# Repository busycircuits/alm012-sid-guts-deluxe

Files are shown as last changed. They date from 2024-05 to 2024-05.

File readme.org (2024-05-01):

* ALM012 SID GUTS DELUXE

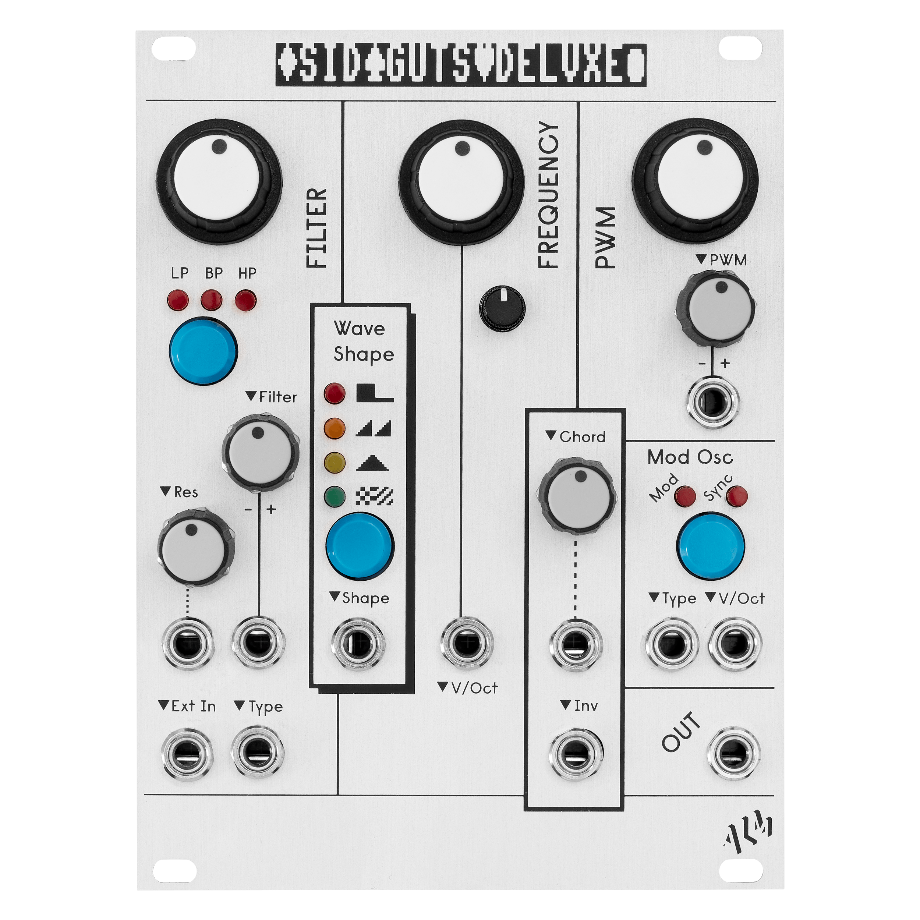
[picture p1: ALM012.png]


** Introduction

The MOS Technology 6581/8580 ‘Sound Interface Device’ chip, aka the ‘SID’, was the sound generator chip used in the Commodore 64 home computer – the greatest selling home computer of all time.  The SID, by the means of 3 wavetable oscillators, a real analogue multi mode filter, an ADSR and various cross modulation options, provided the soundtrack to a generations gaming and perhaps many peoples first exposure to real sound synthesis. The SID’s unique musical aesthetic has lasted well beyond the lifetime of the C64 re-imagined in standalone products such as the SID Station and with in the computer via sophisticated software emulation.

The ALM Busy Circuits ‘SID GUTS DELUXE’ takes the legendary SID chip and brings it into the eurorack modular environment. By use of a real (or emulated) SID chip the classic sound is taken in a new direction with the levels of direct and voltage control only a modular system can offer.

The module features voltage control over numerous SID parameters including the classic PWM, Filter type, cut off, resonance and external input, waveform selection, secondary mod oscillator with ring and sync modulation, voltage per octave tracking and a 3 voice chord mode with inversion. 

The ‘SID GUTS DELUXE’ improves upon the original SID GUTS and was originally released 2014. In 2024 we ended production and have made the firmware and design files open source for anyone to build their own derivative. The files are available in this repository. 

Note you will need a donor SID chip for the module to work. Any real SID chip should work as should most emulated clones (Swin Sid etc). 

*PLEASE NOTE EVERYTHING IS PROVIDED AS IS. WE ARE UNABLE PROVIDE ANY SUPPORT TO ANYONE ATTEMPTING TO USE THESE FILES*

** Building and flashing the firmware

You'll need a basic 'usbtiny' AVR programmer.

You'll need to install avr-gcc and avrdude.

/(On mac using brew..)/
#+BEGIN_SRC
brew tap osx-cross/avr
brew install avr-gcc
brew install avrdude
#+END_SRC

Type 'make' in the firmare/ directory to compile the source code and
then run 'make ispload' (with your programmer connected) to program the
SID GUTS.

** License

Code: MIT license.

Hardware: cc-by-sa-3.0

** Guidelines for derivative works

*ALM is a registered trademark.*

The name "ALM" should not be used on any of the derivative works you create from these files.

We kindly ask to do not name any derivatives 'SID GUTS' but give it a new name.

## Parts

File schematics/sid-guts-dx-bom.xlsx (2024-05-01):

Qty | Parts | Value | Device | Package | SOLDERED REAR | Description / Notes | Mouser Part Num | RS Part Num | Other Part Num
7 | CHORD, FILTER, FILTER_ATT, FREQ_COARSE, PWM_ATTR, PWM_OFF, RES | 10K | ALPHA-9MMA | EVUF |  | 9 mm Square Rotary Potentiometers
1 | FREQ_FINE | 10K | ALPHA-9MMA |  |  | knurled 9 mm Square Rotary Potentiometer
1 | VCO_TRIM | 10K | TRIM_1234-S64YW | S64YW | Y | Trimmer | 72-T93YB-10K
22 | R2, R4, R9, R10, R12, R13, R14, R22, R25, R29, R31, R32, R33, R34, R36, R39, R41, R42, R44, R58, R60, R76 | 100K | RESISTOR0603 | R0603
1 | R49 | 150k | RESISTOR0603 | R0603
12 | R1, R3, R5, R7, R8, R11, R21, R23, R27, R28, R30, R43 | 10K | RESISTOR0603 | R0603
1 | R24 | 200K | RESISTOR0603 | R0603
9 | R80, R81, R82, R83, R16, R17, R18, R19, R20 | 330 | RESISTOR0603 | R0603
4 | R26, R37, R63, R62 | 2.2K | RESISTOR0603 | R0603
1 | R38 | 1K | RESISTOR0603 | R0603
1 | R57 | 1M | RESISTOR0603 | R0603
1 | R6 | 1k | RESISTOR0603 | R0603
3 | R15, R35, R40 | 49.9k | RESISTOR0603 | R0603
1 | R59 | 43K | RESISTOR0603 | R0603
19 | C3, C7, C8, C9, C13, C14, C15, C16, C17, C18, C22, C23, C24, C25, C26, C27, C29, C31, C32 | 100n | CAPACITOR0603 | C0603
3 | C30, C11, C21 | 1n | CAPACITOR0603 | C0603
3 | C6, C10, C28 | 1uf | CPOL-EUB | PANASONIC_B |  | POLARIZED CAPACITOR, European symbol
3 | C1, C2, C12 | 10uf | CPOL-EUB | PANASONIC_B |  | POLARIZED CAPACITOR, European symbol
2 | C19, C20 | 18pf | CAPACITOR0603 | C0603
1 | IC4 | 74HC595D | 74HC595D | SO16 |  | 8-bit SHIFT REGISTER, output latch | 511-M74HC595YRM13TR
1 | IC3 | 74LS174D | 74LS174D | SO16 |  | Hex D type FLIP FLOP, clear |  |  | Farnell 175-0034
1 | IC6 | ATMEGA644A | ATMEGA644A | TQFP44 |  | ATMEGA644PV-10AU |  | 715-3814 | Farnell 1972104
1 | IC1 | DG406CWI | DG406CWI | SO28L |  | ANALOG MULTIPLEXER | 781-DG406DW-E3
4 | IC5, IC7, IC8, IC10 | TL072D | TL072D | SO08 |  | OP AMP | 595-TL072CDR
1 | IC9 | MCP3202ST | MCP3202ST | TSSOP8 |  | MCP3202-CI/ST Dual Channel 12-Bit A/D Converter with SPI Serial Interface | 579-MCP3202-CI/ST
1 | IC2 | SOCKET | MOS6581 | DIL-28 | Y | DIL-28 Wide SOCKET - No IC |  |  | Rapid 22-0115
1 | IC11 | PROP | AD8532 | SO08 |  | OP AMP | 584-AD8532ARZ-R
1 | U3 | 7805 | VREG-7805-DPAK2 | VREG-7805-DPAK2 | Y |  |  | 714-0657
1 | U4 | 7809 | VREG-7809-DPAK2 | VREG-7809-DPAK2 | Y |  | 511-L7809CD2T-TR
1 | U2 | ADR02BUJZ-R2 | ADR02BUJZ-R2 | TSOT-5 ? |  | ADR02BUJZ-R2 Ultracompact, Precision 5.0 Voltage References |  |  | This should be ADR02AUJZ-REEL7
2 | D1, D2 | RS 301-906 | DIODESMB | SMB-DIODE |  | Diode | 621-B130LB-F
2 | D3, D4, |  | DIODE-SOD123 | SOD123 |  | DIODE |  | 700-3671
2 | D5, D6 |  |  | SOD123 |  | Diode | 512-MBR0520L
9 | FHI, FLO, FMID, LED_RING, LED_SYNC, NOISE, PULSE, SAW, TRI | LED3MM | LED3MM | LED3MM |  | All RED except NOISE green, TRI yellow, SAW orange
1 | SV5 | M05X2PTH | M05X2PTH |  | Y | Header 5x2
1 | Y2 |  | CRYSTALSMD | HC49UP |  | 16 Mhz Crystal |  |  | Farnell 184-2294
1 | JP3 |  | JP3E | JP3 | Y | 3 Pin header for jumper
2 | C4, C5 |  |  |  | Y | Capacitor SOCKET - 2.54MM SINGLE ROW HEADER 3 PIN with middle pin clipped.
3 | FI, RS, WF | 3FT1D | 3FT1D | 3FT |  | Mulitmec - 3FT1D
12 | J_CHORD_INV, J_CV_RINGSYNC, J_FILTER, J_FILTER_IN, J_MOD_TYPE, J_OUT, J_PWM, J_RES, J_WAVEFORM, CHORD_IN, J_CV, VCA_IN | WQP-PJ301M-12_JACK | WQP-PJ301M-12_JACK | WQP-PJ301M-12_JACK |  | Jacks
2 | TX, XWAVES |  | M02PTH | 1X02 |  | NOT NEEDED
1 | PGM | AVR_ISP | AVR_SPI_PRG_6PTH | 2X3 |  | NOT NEEDED

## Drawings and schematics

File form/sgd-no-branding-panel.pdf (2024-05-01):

# SGD

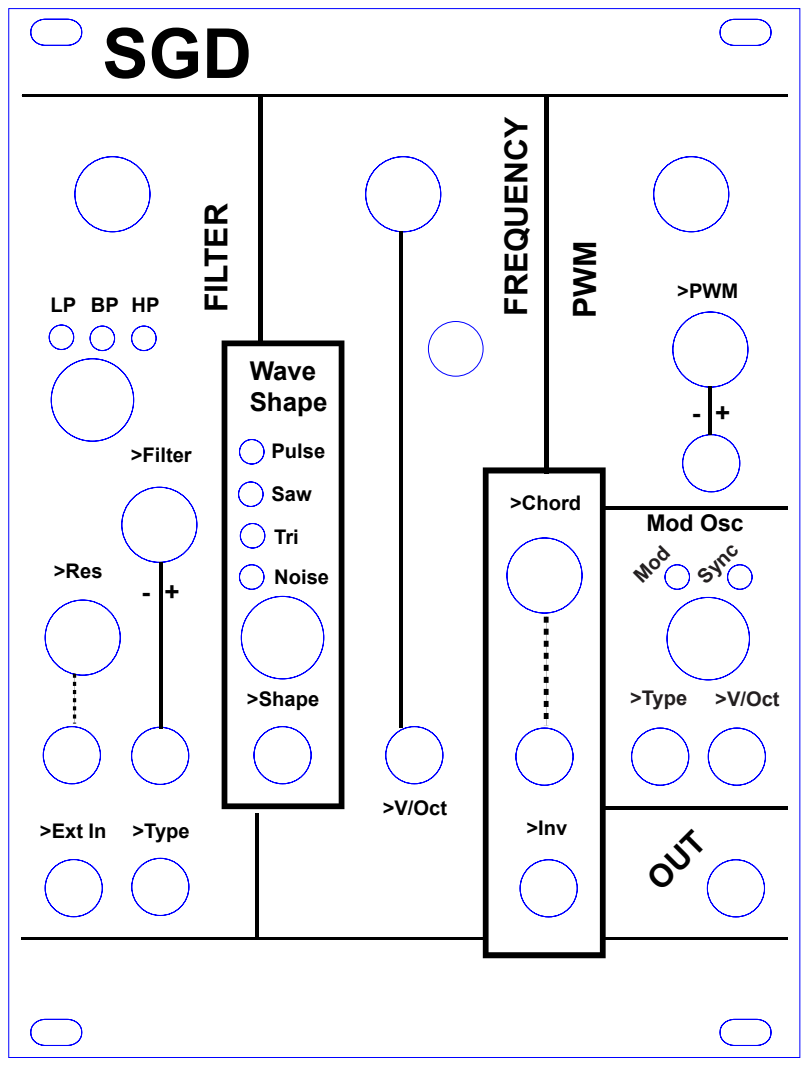
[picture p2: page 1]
OUT; Wave Shape; >Shape; >Res; >Filter; >V/Oct; >Chord; >Ext In >Type; >Inv; >Type >V/Oct; Mod; Sync; FILTER; FREQUENCY; PWM; >PWM; Mod Osc; Pulse; Saw; Tri Noise

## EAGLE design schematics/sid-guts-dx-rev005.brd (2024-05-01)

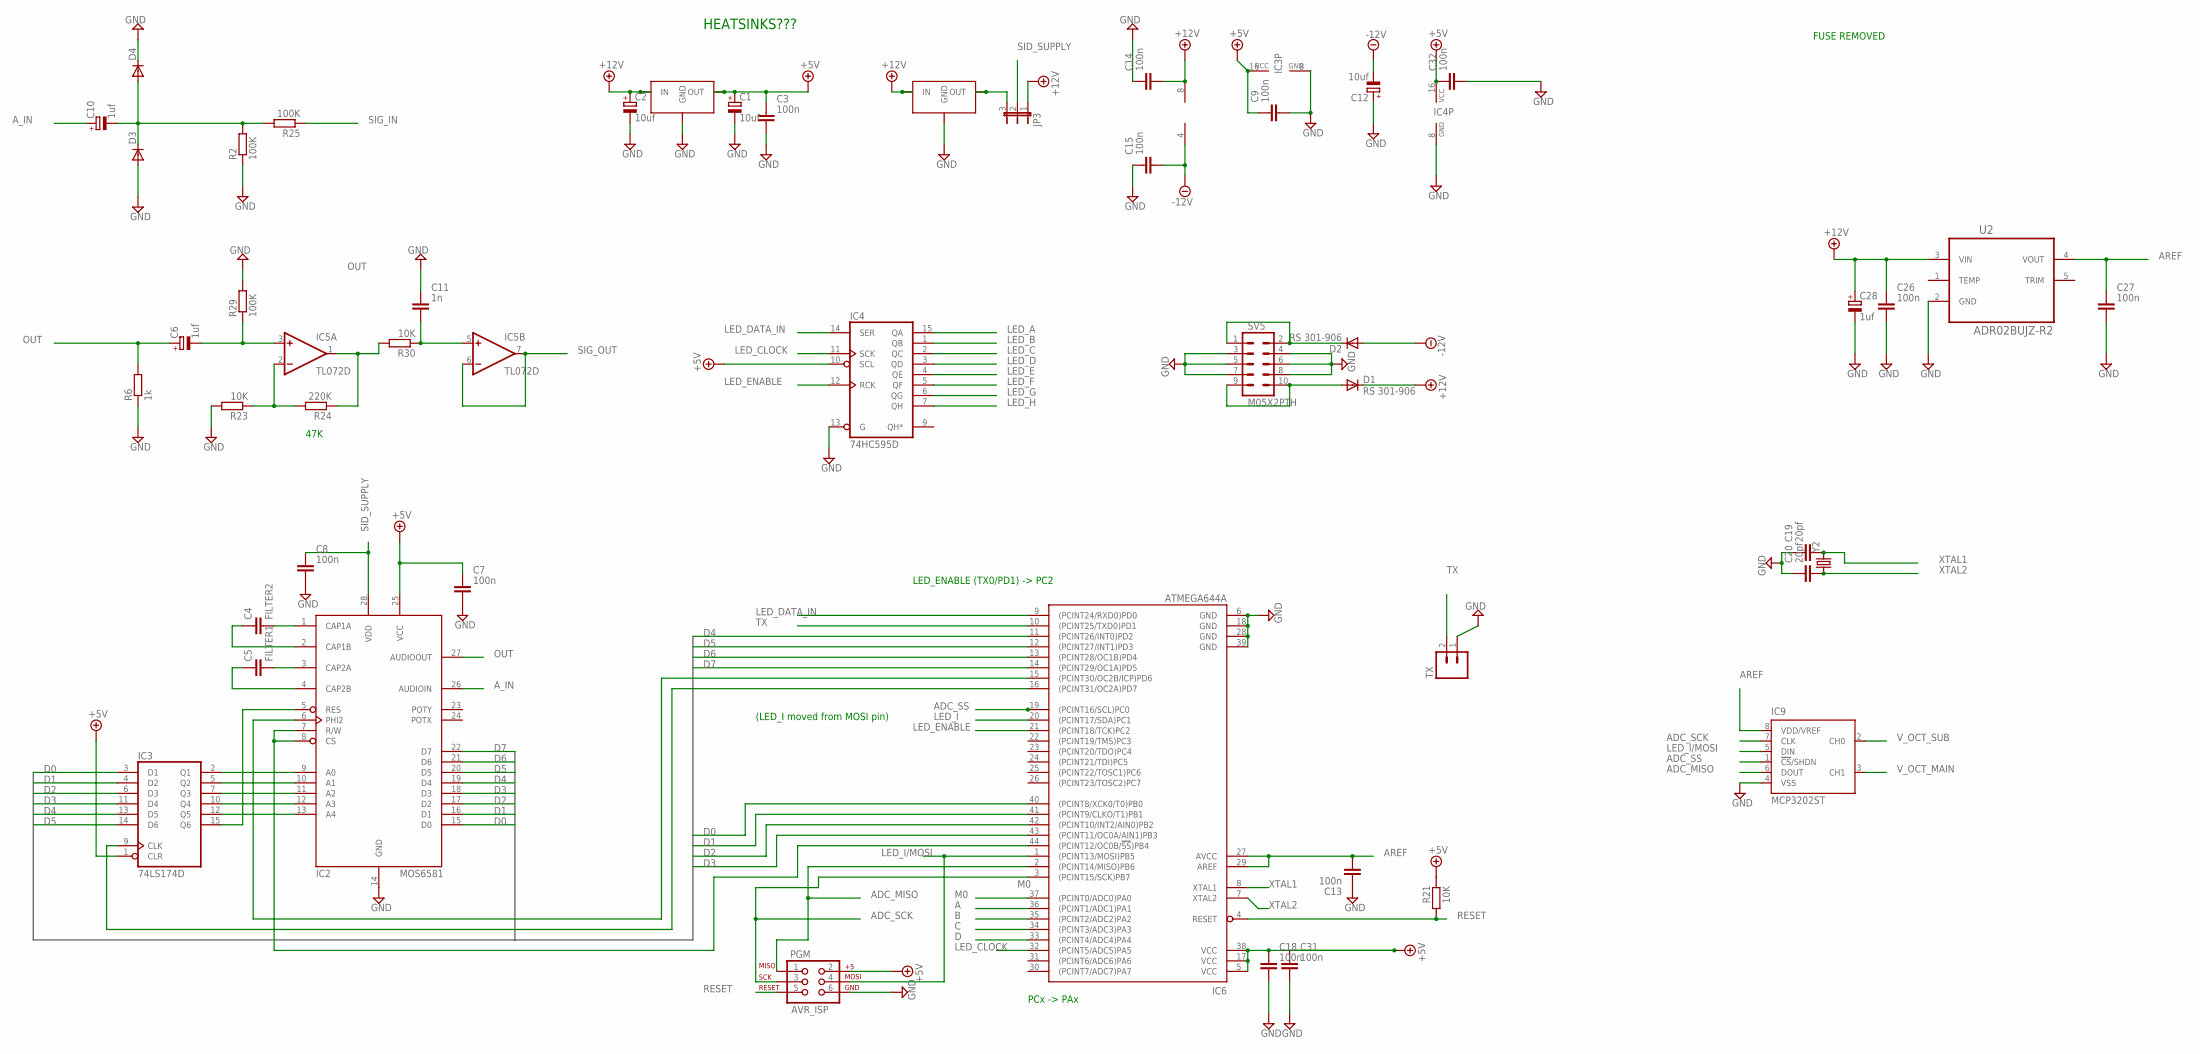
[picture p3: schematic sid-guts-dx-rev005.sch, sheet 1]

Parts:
C1, C2, C12: 10uf; PANASONIC_B
C3, C7, C8, C9, C13, C14, C15, C18, C26, C27, C31, C32: 100n; C0603
C4: FILTER2; C050-025X075
C5: FILTER1; C050-025X075
C6, C10, C28: 1uf; PANASONIC_B
C11: 1n; C0603
C19, C20: 20pf; C0603
D1, D2: RS 301-906; SMB-DIODE
D3, D4: DIODE-SOD123; SOD123
IC2: MOS6581; DIP-28
IC3: 74LS174D; SO16
IC4: 74HC595D; SO16
IC5: TL072D; SO08
IC6: ATMEGA644A; TQFP44
IC9: MCP3202ST; TSSOP8
JP3: JP2E; JP2
PGM: AVR_ISP; 2X3
R2, R25, R29: 100K; R0603
R6: 1k; R0603
R21, R23, R30: 10K; R0603
R24: 220K; R0603
SV5: M05X2PTH; AVR_ICSP
TX: M02PTH; 1X02
U2: ADR02BUJZ-R2; SOT95P280X100-5N
U3: 7805; VREG-7805-DPAK2
U4: 7905; VREG-7805-DPAK2
Y2: CRYSTALSMD; HC49UP

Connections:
+5V: C1.+, C3.1, C7.1, C9.1, C18.1, C31.1, C32.1, IC2.25 (VCC), IC3.1 (CLR), IC3.16 (VCC), IC4.10 (SCL), IC4.16 (VCC), IC6.5 (VCC), IC6.17 (VCC), IC6.38 (VCC), PGM.2, R21.2, U3.VOUT (OUT); also elsewhere on the board
+12V: C2.+, C14.2, C26.1, C28.+, D1.C, IC5.8 (V+), JP3.1, U2.3 (VIN), U3.VIN (IN), U4.VIN (IN); also elsewhere on the board
-12V: C12.-, C15.2, D2.A, IC5.4 (V-); also elsewhere on the board
A: IC6.36 ((PCINT1/ADC1)PA1); also elsewhere on the board
ADC_MISO: IC6.2 ((PCINT14/MISO)PB6), IC9.6 (DOUT), PGM.1
ADC_SCK: IC6.3 ((PCINT15/SCK)PB7), IC9.7 (CLK), PGM.3
ADC_SS: IC6.19 ((PCINT16/SCL)PC0), IC9.1 (!CS!/SHDN)
AREF: C13.2, C27.1, IC6.27 (AVCC), IC6.29 (AREF), IC9.8 (VDD/VREF), U2.4 (VOUT)
A_IN: C10.+, IC2.26 (AUDIOIN)
B: IC6.35 ((PCINT2/ADC2)PA2); also elsewhere on the board
C: IC6.34 ((PCINT3/ADC3)PA3); also elsewhere on the board
CS/RW: IC2.7 (R/W), IC2.8 (CS), IC6.44 ((PCINT12/OC0B/!SS!)PB4)
D: IC6.33 ((PCINT4/ADC4)PA4); also elsewhere on the board
D0: IC2.15 (D0), IC3.3 (D1), IC6.40 ((PCINT8/XCK0/T0)PB0)
D1: IC2.16 (D1), IC3.4 (D2), IC6.41 ((PCINT9/CLKO/T1)PB1)
D2: IC2.17 (D2), IC3.6 (D3), IC6.42 ((PCINT10/INT2/AIN0)PB2)
D3: IC2.18 (D3), IC3.11 (D4), IC6.43 ((PCINT11/OC0A/AIN1)PB3)
D4: IC2.19 (D4), IC3.13 (D5), IC6.11 ((PCINT26/INT0)PD2)
D5: IC2.20 (D5), IC3.14 (D6), IC6.12 ((PCINT27/INT1)PD3)
D6: IC2.21 (D6), IC6.13 ((PCINT28/OC1B)PD4)
D7: IC2.22 (D7), IC6.14 ((PCINT29/OC1A)PD5)
GND: C1.-, C2.-, C3.2, C7.2, C8.2, C9.2, C11.1, C12.+, C13.1, C14.1, C15.1, C18.2, C19.1, C20.1, C26.2, C27.2, C28.-, C31.2, C32.2, D3.A, D4.C, IC2.14 (GND), IC3.8 (GND), IC4.8 (GND), IC4.13 (G), IC6.6 (GND), IC6.18 (GND), IC6.28 (GND), IC6.39 (GND), IC9.4 (VSS), PGM.6, R2.1, R6.1, R23.2, R29.2, SV5.3, SV5.4, SV5.5, SV5.6, SV5.7, SV5.8, TX.1, U2.2 (GND), U3.GND, U4.GND; also elsewhere on the board
LED_A: IC4.15 (QA); also elsewhere on the board
LED_B: IC4.1 (QB); also elsewhere on the board
LED_C: IC4.2 (QC); also elsewhere on the board
LED_CLOCK: IC4.11 (SCK), IC6.32 ((PCINT5/ADC5)PA5)
LED_D: IC4.3 (QD); also elsewhere on the board
LED_DATA_IN: IC4.14 (SER), IC6.9 ((PCINT24/RXD0)PD0)
LED_E: IC4.4 (QE); also elsewhere on the board
LED_ENABLE: IC4.12 (RCK), IC6.21 ((PCINT18/TCK)PC2)
LED_F: IC4.5 (QF); also elsewhere on the board
LED_G: IC4.6 (QG); also elsewhere on the board
LED_H: IC4.7 (QH); also elsewhere on the board
LED_I: IC6.20 ((PCINT17/SDA)PC1); also elsewhere on the board
LED_I/MOSI: IC6.1 ((PCINT13/MOSI)PB5), IC9.5 (DIN), PGM.4
M0: IC6.37 ((PCINT0/ADC0)PA0); also elsewhere on the board
unnamed: D2.C, SV5.1, SV5.2
unnamed: JP3.3, U4.VOUT (OUT)
unnamed: D1.A, SV5.9, SV5.10
unnamed: C4.2, IC2.1 (CAP1A)
unnamed: C4.1, IC2.2 (CAP1B)
unnamed: C5.2, IC2.3 (CAP2A)
unnamed: C5.1, IC2.4 (CAP2B)
unnamed: IC2.9 (A0), IC3.2 (Q1)
unnamed: IC2.10 (A1), IC3.5 (Q2)
unnamed: IC2.11 (A2), IC3.7 (Q3)
unnamed: IC2.12 (A3), IC3.10 (Q4)
unnamed: IC2.13 (A4), IC3.12 (Q5)
unnamed: IC2.5 (RES), IC3.15 (Q6)
unnamed: IC5.1 (OUT), R24.1, R30.2
unnamed: IC3.9 (CLK), IC6.16 ((PCINT31/OC2A)PD7)
unnamed: C6.-, IC5.3 (+IN), R29.1
unnamed: IC5.2 (-IN), R23.1, R24.2
unnamed: IC2.6 (PHI2), IC6.15 ((PCINT30/OC2B/ICP)PD6)
unnamed: C10.-, D3.C, D4.A, R2.2, R25.2
unnamed: C11.2, IC5.5 (+IN), R30.1
OUT: C6.+, IC2.27 (AUDIOOUT), R6.2
RESET: IC6.4 (RESET), PGM.5, R21.1
SID_SUPPLY: C8.1, IC2.28 (VDD), JP3.2
SIG_IN: R25.1; also elsewhere on the board
SIG_OUT: IC5.6 (-IN), IC5.7 (OUT); also elsewhere on the board
TX: IC6.10 ((PCINT25/TXD0)PD1), TX.2
V_OCT_MAIN: IC9.3 (CH1); also elsewhere on the board
V_OCT_SUB: IC9.2 (CH0); also elsewhere on the board
XTAL1: C19.2, IC6.8 (XTAL1), Y2.2
XTAL2: C20.2, IC6.7 (XTAL2), Y2.1

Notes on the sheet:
47K
PCx -> PAx
FUSE REMOVED
HEATSINKS???
(LED_I moved from MOSI pin)
LED_ENABLE (TX0/PD1) -> PC2

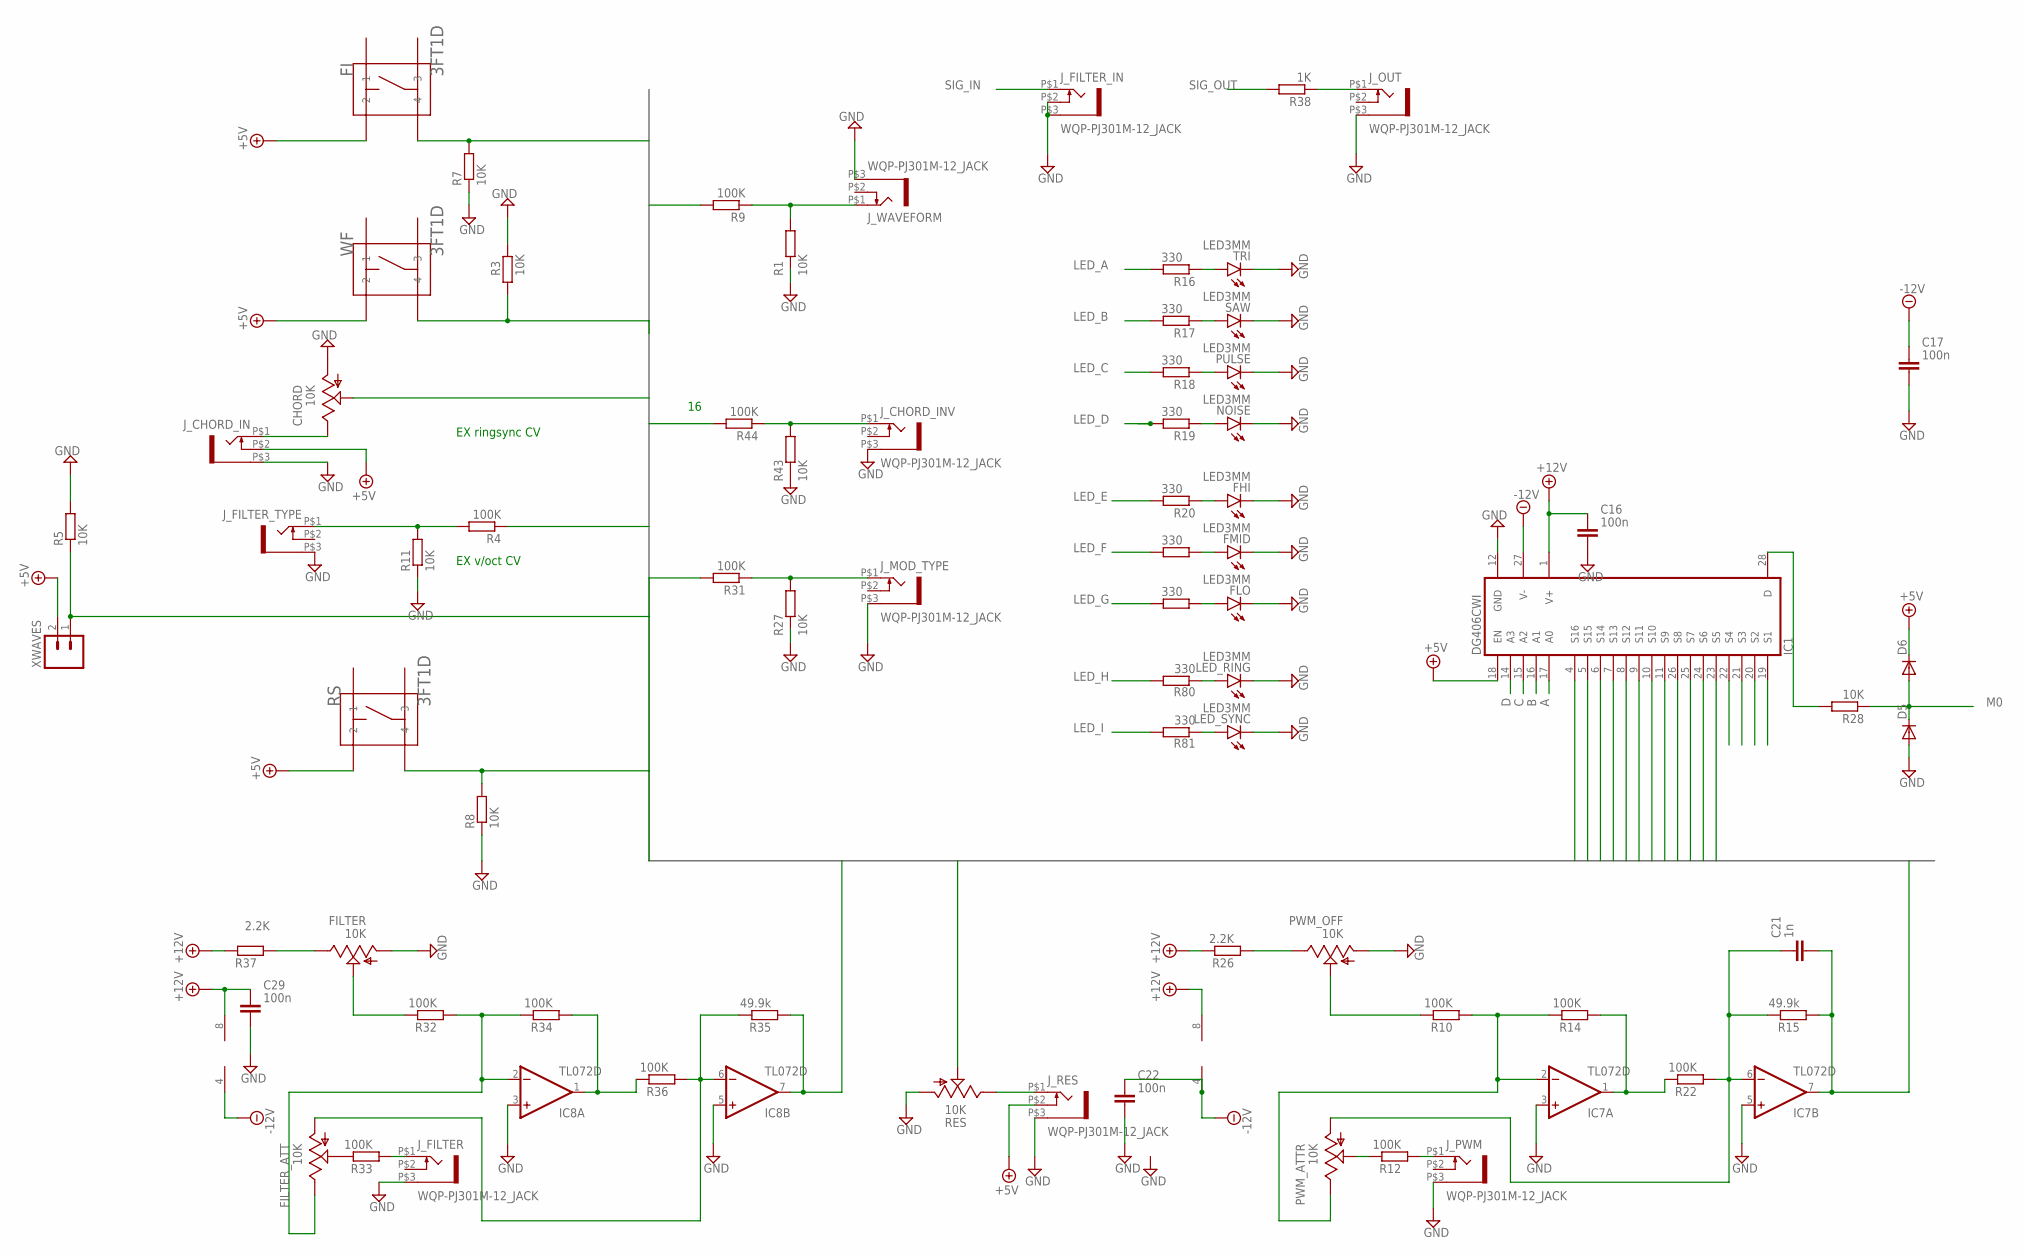
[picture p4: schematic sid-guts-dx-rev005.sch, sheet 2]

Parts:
C16, C17, C22, C29: 100n; C0603
C21: 1n; C0603
CHORD: 10K; EVUF
D5, D6: DIODE-SOD123; SOD123
FHI: LED3MM
FI: 3FT1D; 3FT
FILTER: 10K; EVUF
FILTER_ATT: 10K; EVUF
FLO: LED3MM
FMID: LED3MM
IC1: DG406CWI; SO28L
IC7, IC8: TL072D; SO08
J_CHORD_IN: WQP-PJ301M-12_JACK
J_CHORD_INV: WQP-PJ301M-12_JACK
J_FILTER: WQP-PJ301M-12_JACK
J_FILTER_IN: WQP-PJ301M-12_JACK
J_FILTER_TYPE: WQP-PJ301M-12_JACK
J_MOD_TYPE: WQP-PJ301M-12_JACK
J_OUT: WQP-PJ301M-12_JACK
J_PWM: WQP-PJ301M-12_JACK
J_RES: WQP-PJ301M-12_JACK
J_WAVEFORM: WQP-PJ301M-12_JACK
LED_RING: LED3MM
LED_SYNC: LED3MM
NOISE: LED3MM
PULSE: LED3MM
PWM_ATTR: 10K; EVUF
PWM_OFF: 10K; EVUF
R1, R3, R5, R7, R8, R11, R27, R28, R43: 10K; R0603
R4, R9, R10, R12, R14, R22, R31, R32, R33, R34, R36, R44: 100K; R0603
R15, R35: 49.9k; R0603
R16, R17, R18, R19, R20, R80, R81, R82, R83: 330; R0603
R26, R37: 2.2K; R0603
R38: 1K; R0603
RES: 10K; EVUF
RS: 3FT1D; 3FT
SAW: LED3MM
TRI: LED3MM
WF: 3FT1D; 3FT
XWAVES: M02PTH; 1X02

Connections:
+5V: D6.C, FI.P$2 (2), IC1.18 (EN), J_CHORD_IN.P$2 (3), J_RES.P$2 (3), RS.P$2 (2), WF.P$2 (2), XWAVES.2; also elsewhere on the board
+12V: C16.1, C29.1, IC1.1 (V+), IC7.8 (V+), IC8.8 (V+), R26.2, R37.2; also elsewhere on the board
-12V: C17.1, C22.1, IC1.27 (V-), IC7.4 (V-), IC8.4 (V-); also elsewhere on the board
A: IC1.17 (A0); also elsewhere on the board
B: IC1.16 (A1); also elsewhere on the board
C: IC1.15 (A2); also elsewhere on the board
D: IC1.14 (A3); also elsewhere on the board
EXP1: IC1.22 (S4)
EXP3: IC1.20 (S2)
EXP5: IC1.21 (S3)
EXP6: IC1.19 (S1)
GND: C16.2, C17.2, C22.2, C29.2, CHORD.1 (A), D5.A, FHI.K (C), FILTER.1 (A), FLO.K (C), FMID.K (C), IC1.12 (GND), IC7.3 (+IN), IC7.5 (+IN), IC8.3 (+IN), IC8.5 (+IN), J_CHORD_IN.P$3 (1), J_CHORD_INV.P$3 (1), J_FILTER.P$3 (1), J_FILTER_IN.P$2 (3), J_FILTER_IN.P$3 (1), J_FILTER_TYPE.P$3 (1), J_MOD_TYPE.P$3 (1), J_OUT.P$3 (1), J_PWM.P$3 (1), J_RES.P$3 (1), J_WAVEFORM.P$3 (1), LED_RING.K (C), LED_SYNC.K (C), NOISE.K (C), PULSE.K (C), PWM_OFF.1 (A), R1.1, R3.2, R5.2, R7.1, R8.1, R11.1, R27.1, R43.1, RES.1 (A), SAW.K (C), TRI.K (C); also elsewhere on the board
I5: C21.2, IC1.23 (S5), IC7.7 (OUT), R15.1
I6: IC1.24 (S6), RES.2 (S)
I7: IC1.25 (S7), IC8.7 (OUT), R35.1
I8: FI.P$4 (4), IC1.26 (S8), R7.2
I9: IC1.11 (S9), R5.1, XWAVES.1
I10: IC1.10 (S10), R8.2, RS.P$4 (4)
I11: IC1.9 (S11), R4.1
I12: CHORD.2 (S), IC1.8 (S12)
I13: IC1.7 (S13), R9.2
I14: IC1.6 (S14), R3.1, WF.P$4 (4)
I15: IC1.5 (S15), R31.2
I16: IC1.4 (S16), R44.2
LED_A: R16.2; also elsewhere on the board
LED_B: R17.2; also elsewhere on the board
LED_C: R18.2; also elsewhere on the board
LED_D: R19.2; also elsewhere on the board
LED_E: R20.2; also elsewhere on the board
LED_F: R83.2; also elsewhere on the board
LED_G: R82.2; also elsewhere on the board
LED_H: R80.2; also elsewhere on the board
LED_I: R81.2; also elsewhere on the board
M0: D5.C, D6.A, R28.1; also elsewhere on the board
unnamed: FHI.A, R20.1
unnamed: CHORD.3 (E), J_CHORD_IN.P$1 (2)
unnamed: FMID.A, R83.1
unnamed: FLO.A, R82.1
unnamed: IC1.28 (D), R28.2
unnamed: J_WAVEFORM.P$1 (2), R1.2, R9.1
unnamed: LED_RING.A, R80.1
unnamed: LED_SYNC.A, R81.1
unnamed: J_FILTER_TYPE.P$1 (2), R4.2, R11.2
unnamed: J_RES.P$1 (2), RES.3 (E)
unnamed: PWM_OFF.2 (S), R10.2
unnamed: IC7.2 (-IN), PWM_ATTR.3 (E), R10.1, R14.2
unnamed: R16.1, TRI.A
unnamed: R17.1, SAW.A
unnamed: PULSE.A, R18.1
unnamed: NOISE.A, R19.1
unnamed: J_PWM.P$1 (2), R12.1
unnamed: PWM_ATTR.2 (S), R12.2
unnamed: IC7.1 (OUT), R14.1, R22.2
unnamed: C21.1, IC7.6 (-IN), PWM_ATTR.1 (A), R15.2, R22.1
unnamed: PWM_OFF.3 (E), R26.1
unnamed: J_MOD_TYPE.P$1 (2), R27.2, R31.1
unnamed: FILTER.2 (S), R32.2
unnamed: FILTER_ATT.3 (E), IC8.2 (-IN), R32.1, R34.2
unnamed: J_FILTER.P$1 (2), R33.1
unnamed: IC8.1 (OUT), R34.1, R36.2
unnamed: FILTER_ATT.1 (A), IC8.6 (-IN), R35.2, R36.1
unnamed: FILTER.3 (E), R37.1
unnamed: J_OUT.P$1 (2), R38.1
unnamed: FILTER_ATT.2 (S), R33.2
unnamed: J_CHORD_INV.P$1 (2), R43.2, R44.1
SIG_IN: J_FILTER_IN.P$1 (2); also elsewhere on the board
SIG_OUT: R38.2; also elsewhere on the board

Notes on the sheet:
EX v/oct CV
EX ringsync CV

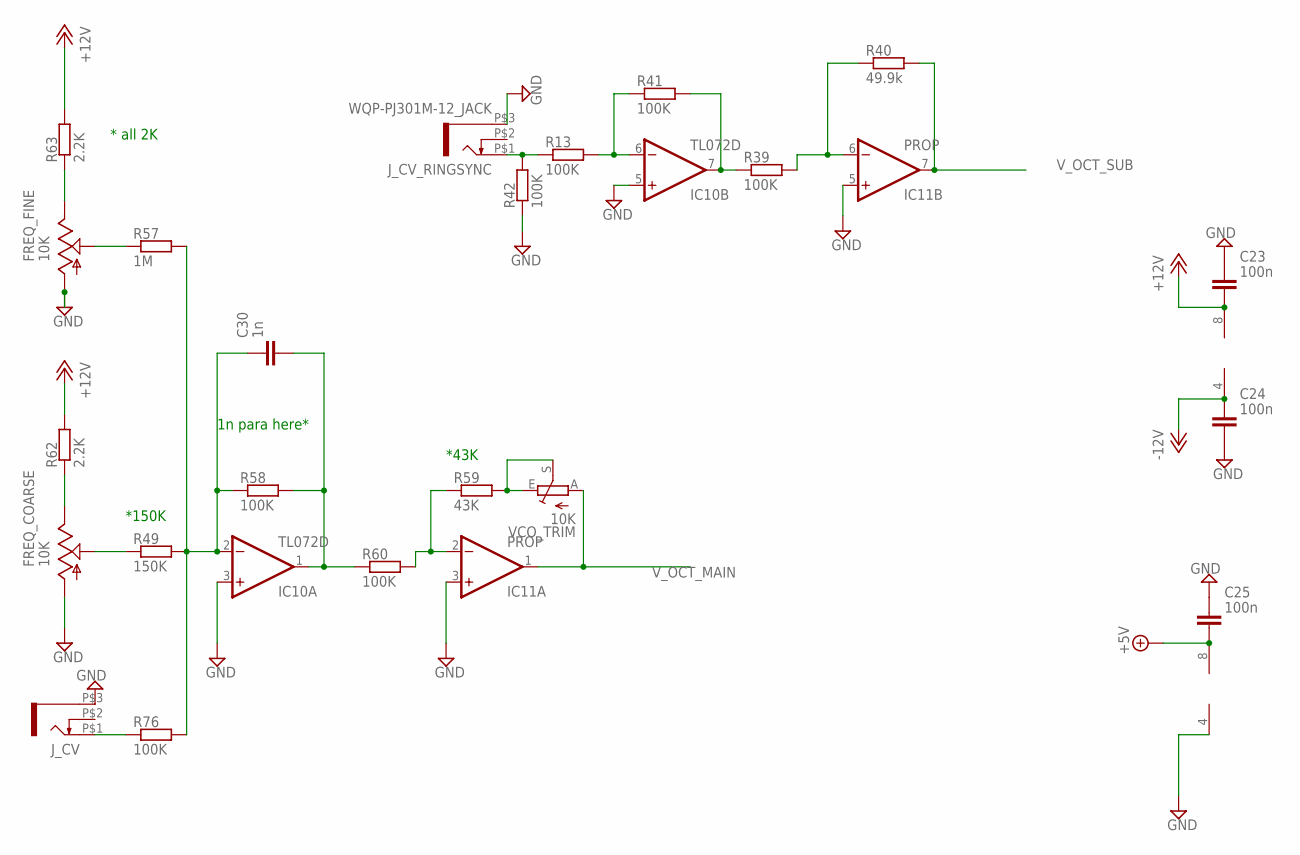
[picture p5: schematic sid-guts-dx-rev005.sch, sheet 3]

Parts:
C23, C24, C25: 100n; C0603
C30: 1n; C0603
FREQ_COARSE: 10K; EVUF
FREQ_FINE: 10K; EVUF
IC10: TL072D; SO08
IC11: PROP; SO08
J_CV: WQP-PJ301M-12_JACK
J_CV_RINGSYNC: WQP-PJ301M-12_JACK
R13, R39, R41, R42, R58, R60, R76: 100K; R0603
R40: 49.9k; R0603
R49: 150K; R0603
R57: 1M; R0603
R59: 43K; R0603
R62, R63: 2.2K; R0603
VCO_TRIM: 10K; S64YW

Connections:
+5V: C25.2, IC11.8 (V+); also elsewhere on the board
+12V: C23.2, IC10.8 (V+), R62.2, R63.2; also elsewhere on the board
-12V: C24.1, IC10.4 (V-); also elsewhere on the board
GND: C23.1, C24.2, C25.1, FREQ_COARSE.1 (A), FREQ_FINE.1 (A), IC10.3 (+IN), IC10.5 (+IN), IC11.3 (+IN), IC11.4 (V-), IC11.5 (+IN), J_CV.P$3 (1), J_CV_RINGSYNC.P$3 (1), R42.1; also elsewhere on the board
unnamed: IC10.7 (OUT), R39.1, R41.2
unnamed: IC10.6 (-IN), R13.2, R41.1
unnamed: J_CV_RINGSYNC.P$1 (2), R13.1, R42.2
unnamed: IC11.6 (-IN), R39.2, R40.1
unnamed: J_CV.P$1 (2), R76.1
unnamed: FREQ_COARSE.2 (S), R49.1
unnamed: C30.1, IC10.2 (-IN), R49.2, R57.2, R58.1, R76.2
unnamed: FREQ_FINE.2 (S), R57.1
unnamed: C30.2, IC10.1 (OUT), R58.2, R60.1
unnamed: IC11.2 (-IN), R59.1, R60.2
unnamed: R59.2, VCO_TRIM.E, VCO_TRIM.S
unnamed: FREQ_COARSE.3 (E), R62.1
unnamed: FREQ_FINE.3 (E), R63.1
V_OCT_MAIN: IC11.1 (OUT), VCO_TRIM.A; also elsewhere on the board
V_OCT_SUB: IC11.7 (OUT), R40.2; also elsewhere on the board

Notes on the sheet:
*43K
* all 2K
1n para here*
*150K

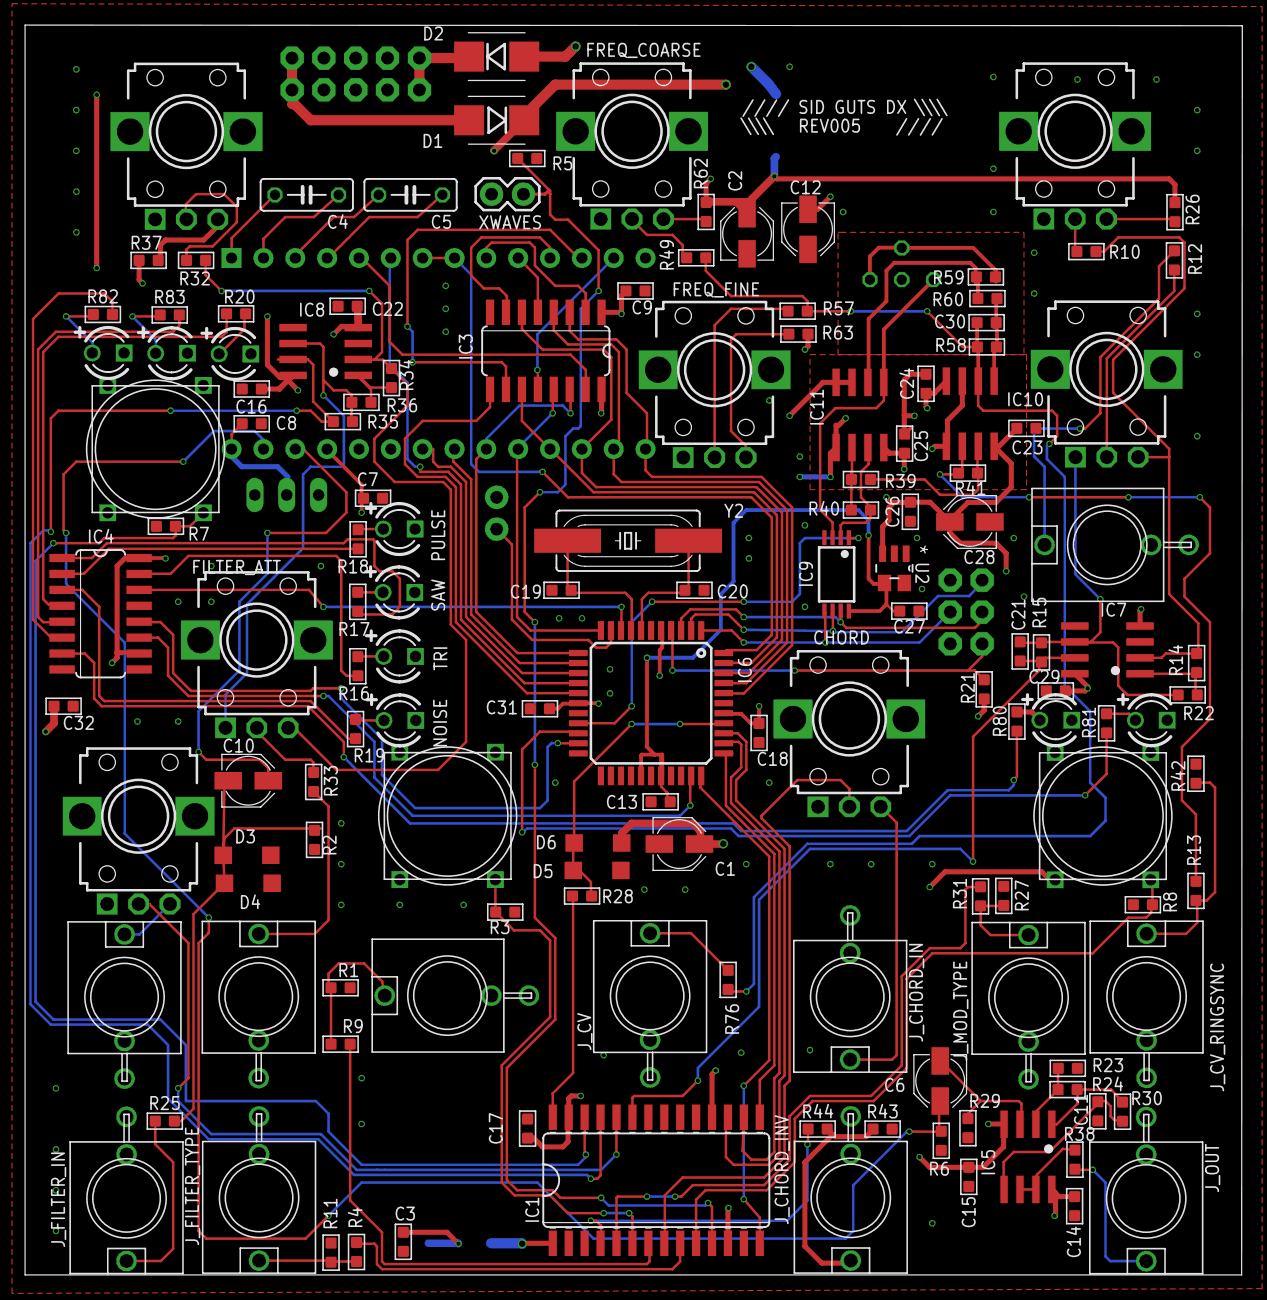
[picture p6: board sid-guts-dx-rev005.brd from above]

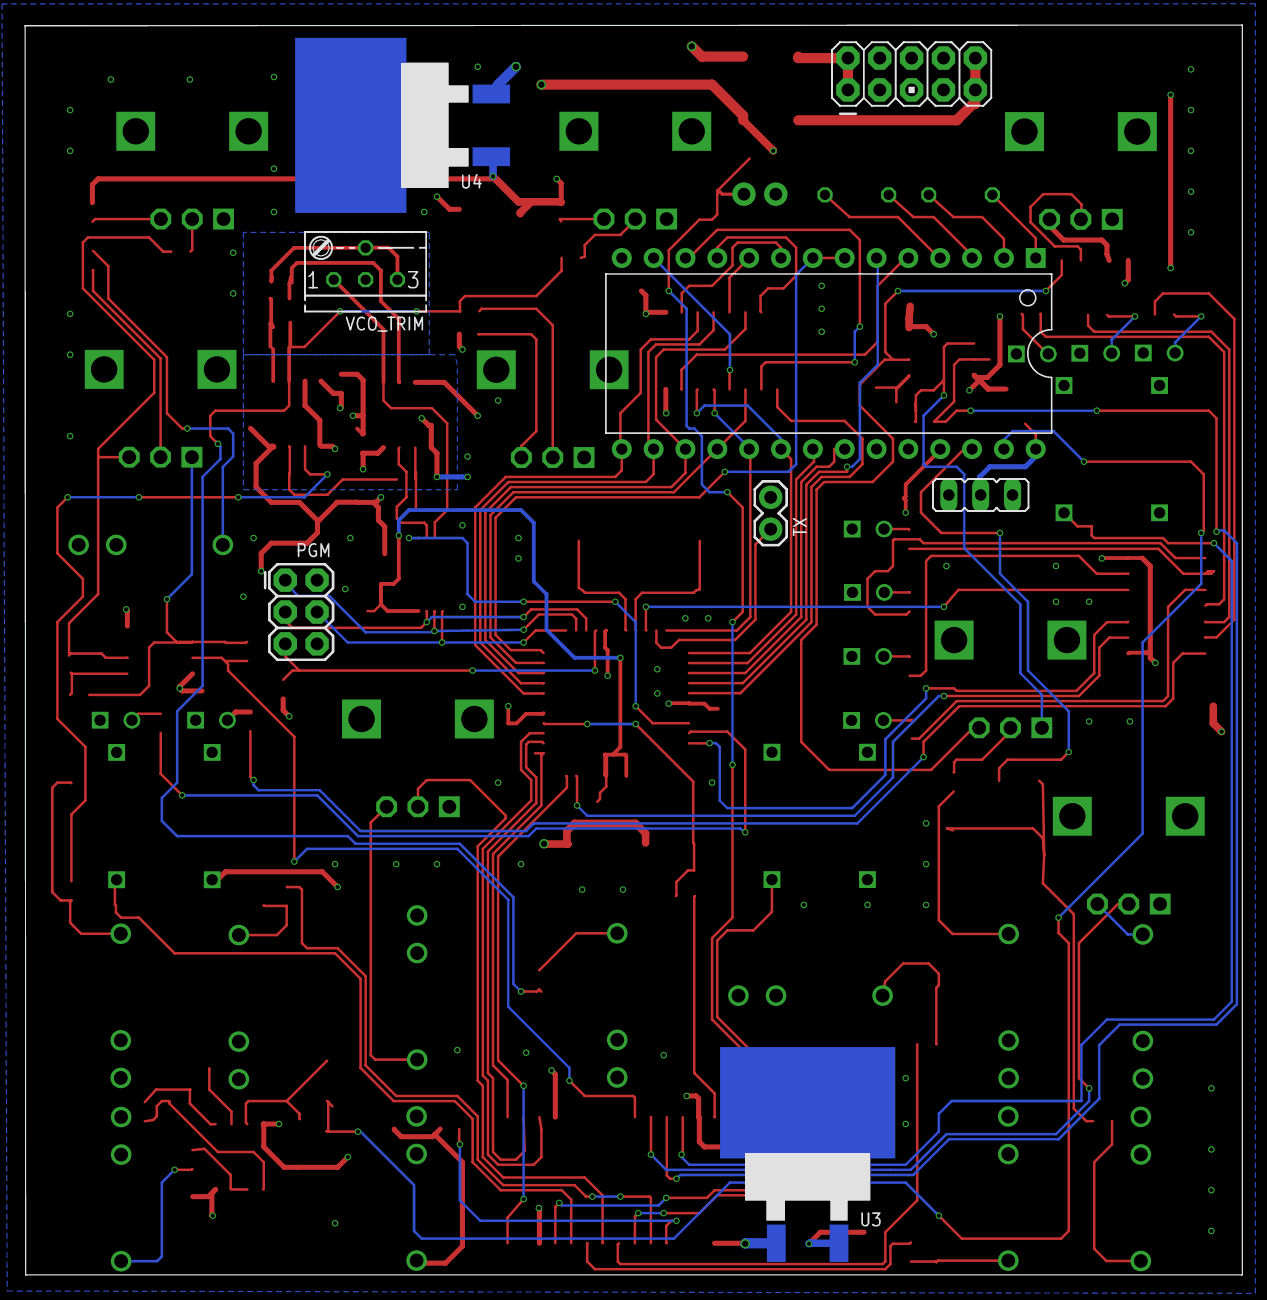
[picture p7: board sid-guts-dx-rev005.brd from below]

Board: 4 copper layers, 97.1 x 99.7 mm, 147 parts (8 on the bottom side), 122 nets.

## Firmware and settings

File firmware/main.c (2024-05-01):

/*
*   ALM012 'SID GUTS DULUXE' firmware 
*   
*   Copyright (c) 2014 ALM Co Ltd
*
*   Parts based on code written by Alexis Kotlowy, released in Public Domain. 
*
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
*/

#include "uu.h"
#include <avr/pgmspace.h>
#include <util/delay.h>

#include "lookup.h"

/* AVR Pins */
#define PIN_MULT_IN PIN_A0 
#define PIN_MULT_A PIN_A1
#define PIN_MULT_B PIN_A2 
#define PIN_MULT_C PIN_A3
#define PIN_MULT_D PIN_A4 
#define PIN_LED_I      PIN_C1 
#define PIN_LED_DATA   PIN_D0
#define PIN_LED_CLOCK  PIN_A5
#define PIN_LED_ENABLE PIN_C2
#define PIN_TX PIN_D1

#define PIN_ADC_MOSI     PIN_B5
#define PIN_ADC_MISO     PIN_B6
#define PIN_ADC_SPICLOCK PIN_B7
#define PIN_ADC_SLAVE_SELECT PIN_C0


/* HW Related defines */
#define CCHAN_R 0
#define CCHAN_S 1
#define CCHAN_D 2
#define CCHAN_A 3
#define CCHAN_NONE 8

#define CCHAN_PWM 4
#define CCHAN_RES 5
#define CCHAN_FILT 6
#define CCHAN_SWITCH_RINGSYNC 9
#define CCHAN_FILTER_TYPE_CV 10
#define CCHAN_CHORD_CV 11
#define CCHAN_EXT_WAVEFORMS 8
#define CCHAN_SWITCH_FILTER 7
#define CCHAN_RINGSYNC 14 // to mod sel
#define CCHAN_SWITCH_WAVEFORM 13
#define CCHAN_WAVEFORM 12
#define CCHAN_CHORD_INV 15

/* LED Flags */
#define LED_TRI   (1<<0)
#define LED_SAW   (1<<1)
#define LED_PULSE (1<<2)
#define LED_NOISE (1<<3)
#define LED_HI    (1<<4)
#define LED_MID   (1<<5)
#define LED_LO    (1<<6)
#define LED_RING  (1<<7)
#define LED_SYNC  (1<<8)

/* Switch flags */
#define SWITCH_FILTER (1<<2)
#define SWITCH_WAVEFORM (1<<3)
#define SWITCH_RINGSYNC (1<<4)

/* Filter flags */
#define FILTER_LP     0
#define FILTER_BP     1 
#define FILTER_HP     2
#define FILTER_NOTCH  3
#define FILTER_NONE   -1

/* Constants for Waveform */
#define WAVEFORM_NONE 0x0
#define WAVEFORM_TRI 0x1
#define WAVEFORM_SAW 0x2
#define WAVEFORM_PULSE 0x4
#define WAVEFORM_NOISE 0x8

#define WAVEFORM_TRISAW WAVEFORM_TRI|WAVEFORM_SAW
#define WAVEFORM_TRIPULSE WAVEFORM_TRI|WAVEFORM_PULSE
#define WAVEFORM_SAWPULSE WAVEFORM_SAW|WAVEFORM_PULSE
#define WAVEFORM_NOWAVE 0x0  
  
/* OSC3 State */
#define STATE_NONE 0
#define STATE_RING 1
#define STATE_SYNC 2

/* SID Realted */
#define VOLUME 15
/* #define CHAN3_OFF (1<<7) */
#define CHAN3_OFF 0

/* Freq LUT */
#define VOLTS_FREQ_MIN 1304
#define VOLTS_FREQ_MAX 41617

#define VOLTS_FREQ_N 3276

typedef struct _Chord 
{
  byte n_freqs;
  byte denom;
  byte numerator[3];
} 
Chord;

#define N_EXT_WAVEFORMS 7 

uint8_t __ext_waveform_list[] = { WAVEFORM_TRI,
				WAVEFORM_SAW,
				WAVEFORM_PULSE,
				WAVEFORM_NOISE,
				WAVEFORM_TRISAW,
				WAVEFORM_TRIPULSE,
				WAVEFORM_SAWPULSE };


#define N_CHORDS 11

Chord _chords[N_CHORDS] =
  { 

    { 0, 1, { 1 }},  	  /* none */
    { 1, 4, { 5 }},  	  /* Power x2 (5th) */
    { 2, 4, { 5, 6 }}, 	  /* Major FIXME: ADD inverted */
    { 2, 10, { 12, 15 }}, /* Minor FIXME: ADD inverted */
    { 2, 6, {8, 9}},      /* Suspended */
    { 2, 16, {20, 25}},   /* Augmented */
    { 2, 20, { 24, 29 }}, /* Diminished */
    { 1, 1, { 2 }},  	  /* Octave x1 - 1 octave a part */
    { 2, 1, { 2, 3 }},    /* Octave x2 - 2 octave a part */
    { 2, 30, { 31, 33 }}, /* Detune 1 */
    { 2, 50, { 51, 53 }}  /* Detune 2 */
  };

typedef struct _SIDState 
{
  int      waveform;
  int      freq_chan_1;
  int      freq_chan_2;
  int      freq_chan_3;
  int      pulse_width;
  int      filter;
  int      resonance;
  int      filter_type;
  uint8_t  hp,bp,lp;
  uint8_t  chan_3_state;
  bool     gate_off;
  int      volume;
  int      chord_index;
  bool     ext_waveforms;
  uint8_t  filter_mask;
  uint8_t  chord_inv;

  uint8_t  ext_waveforms_idx;
  uint8_t  ext_waveforms_cnt;
  
} SIDstate;

SIDstate _sid;
int16_t _tune_offset = 0;

void cycle ();

void mcp3202_init()
{
  uu_pin_mode(PIN_ADC_MOSI, OUTPUT);
  uu_pin_mode(PIN_ADC_MISO, INPUT);
  uu_pin_mode(PIN_ADC_SPICLOCK, OUTPUT);
  uu_pin_mode(PIN_ADC_SLAVE_SELECT, OUTPUT);
}

int mcp3202_read(byte channel)
{
  int adcvalue = 0;
  byte commandbits = B11010000; //command bits - start, mode, chn, MSBF 

  //allow channel selection
  if (channel)
    commandbits = B11110000;

  uu_pin_digital_write (PIN_ADC_SLAVE_SELECT, LOW); //Select adc

  for (int i=7; i>=4; i--){
    uu_pin_digital_write(PIN_ADC_MOSI,commandbits&1<<i);
    //cycle clock
    uu_pin_digital_write(PIN_ADC_SPICLOCK, HIGH);
    uu_pin_digital_write(PIN_ADC_SPICLOCK, LOW);
  }

  uu_pin_digital_write(PIN_ADC_SPICLOCK, HIGH);    //ignores 1 null bit
  uu_pin_digital_write(PIN_ADC_SPICLOCK, LOW);
  
  //read bits from adc
  for (int i=11; i>=0; i--)
    {
      adcvalue += uu_pin_digital_read(PIN_ADC_MISO)<<i;
      //cycle clock
      uu_pin_digital_write(PIN_ADC_SPICLOCK, HIGH);
      uu_pin_digital_write(PIN_ADC_SPICLOCK, LOW);
    }

  uu_pin_digital_write(PIN_ADC_SLAVE_SELECT, HIGH); //turn off device

  return adcvalue;
}

void 
tuning_save()
{
  uu_interrupts_off();
  eeprom_write_word (1, _tune_offset);
  uu_interrupts_on();
}

void
settings_save()
{
  byte b;

  /* 1 byte for speed... */
  b = (_sid.waveform<<4) 	    /* bits 8-4 */
    |(_sid.filter_type<<2)  /* Filter 4-2  */
    |_sid.chan_3_state;	    /* State  2-1  */

  uu_interrupts_off();
  eeprom_write_byte (0, b);
  uu_interrupts_on();
}

void
settings_load()
{
  byte b;

  b = eeprom_read_byte (0);

  if (b == 0xff) // default erased val.. waveform only goes to 0x80
    {
      _tune_offset = 0;
      return;
    }

  _sid.waveform = (b & 0xf0) >> 4;
  _sid.filter_type = (b & 0x0f) >> 2;
  _sid.chan_3_state = (b & 0x3);

  _tune_offset = eeprom_read_word (1);

  switch (_sid.waveform) 
    {
    case WAVEFORM_NONE:
    case WAVEFORM_TRI:
    case WAVEFORM_SAW: 
    case WAVEFORM_PULSE: 
    case WAVEFORM_NOISE: 
      break;
    default:
      /* Something gone wrong - flash corrupt...? defaults */
      _sid.waveform = WAVEFORM_PULSE;
      break;
    }
}

void leds_set_mask(uint32_t mask)
{
  byte shift_mask = mask & 0xFF;

  if (mask & LED_SYNC)
    uu_pin_digital_write(PIN_LED_I, HIGH);
  else
    uu_pin_digital_write(PIN_LED_I, LOW);

  uu_pin_digital_write(PIN_LED_ENABLE, LOW);
  uu_pin_shift_out(PIN_LED_DATA, PIN_LED_CLOCK, MSBFIRST, shift_mask);  
  uu_pin_digital_write(PIN_LED_ENABLE, HIGH);
}

int analog_read()
{
  uint8_t low, high;
  
  /* switch to ADMUX for (1<<6) - AVcc with external capacitor on AREF pin  */
  ADMUX |= 0; // AREF, Internal Vref turned off  & chan 0 
  
  ADCSRA = (1<<ADEN) | (1<<ADPS2) | (1<<ADPS1);
  /* Start conversion */
  ADCSRA |= (1<<ADSC);
  /* Wait.. */
  while (uu_bit_is_set(ADCSRA, ADSC));
  /* Collect */
  low  = ADCL;
  high = ADCH;

  return (high << 8) | low;
}

void select_chan(int chan)
{
  uu_pin_digital_write (PIN_MULT_A, (chan & 0x01));
  uu_pin_digital_write (PIN_MULT_B, ((chan >> 1) & 0x01));
  uu_pin_digital_write (PIN_MULT_C, ((chan >> 2) & 0x01));
  uu_pin_digital_write (PIN_MULT_D, ((chan >> 3) & 0x01));

  _delay_us(500);
}

int read_chan_analog(int chan)
{
  select_chan(chan);

  return analog_read(); 
}

bool read_chan_digital(int chan)
{
  select_chan(chan);

  return (analog_read() > 512);
}

byte switches_read_mask()
{
  byte button_mask = 0;

  if (read_chan_digital(CCHAN_SWITCH_FILTER))
    button_mask |= SWITCH_FILTER;
    
  if (read_chan_digital(CCHAN_SWITCH_WAVEFORM))
    button_mask |= SWITCH_WAVEFORM;

  if (read_chan_digital(CCHAN_SWITCH_RINGSYNC))
    button_mask |= SWITCH_RINGSYNC;

  return button_mask;
}

void SID_poke (uint8_t port, uint8_t data) 
{
  PORTB = (port & 0x0F) | 0x10;        // Lower bit, keep CS deactive
  PORTD = ((port | 0x20) & 0xF0) >> 2; // Upper bit, reset high
  PORTD |= 0x80;                       // Clock in Address
  _delay_us(10);
  PORTD &= ~(0x80);

  PORTB = (data & 0x0F) | 0x10;  // Lower bit, keep CS deactive
  PORTD = (data & 0xF0) >> 2;    // Upper bit
  PORTB &= ~(0x10);   // Activate /CS
  _delay_us(10);
  PORTB |= 0x10;      // Deactivate /CS
}  

void soundcheck()
{
  int waveforms[] = { WAVEFORM_PULSE, WAVEFORM_SAW, WAVEFORM_TRI, WAVEFORM_NOISE };
  int filters[] = { FILTER_LP, FILTER_BP, FILTER_HP, FILTER_NOTCH };
  int i,j, k;

  /* Test Waveforms */
  for (k=0;k<1;k++)
    {
      unsigned int n,f,d,e;

      SID_poke(4,(WAVEFORM_PULSE<<4)|(0<<2)|(0<<1)|1);

      /* Set pulse width middle */
      SID_poke(2,uu_bit_low_byte(2056));
      SID_poke(3,uu_bit_high_byte(206));

      /* low pass */
      SID_poke(24, (CHAN3_OFF|(0<<6)|(0<<5)|(1<<4)|VOLUME));

      /* resonance */
      SID_poke(23,(8<<4)|9 /* 9 may be safer */);
      f = 1024 << 1;
      SID_poke(21,uu_bit_low_byte(f));     // Set filter value - 11bits
      SID_poke(22, uu_bit_high_byte(f << 5));

      for (j=0;j<4;j++)
	{
	  switch (waveforms[j])
	    {
	    case WAVEFORM_TRI:
	      leds_set_mask(LED_TRI);
	      break;
	    case WAVEFORM_SAW:
	      leds_set_mask(LED_SAW);
	      break;
	    case WAVEFORM_NOISE:
	      leds_set_mask(LED_NOISE);
	      break;
	    case WAVEFORM_PULSE:
	      leds_set_mask(LED_PULSE);
	      break;
	    }

	  for(i=0;i<12;i++) 
	    {
	      f = 100; // pgm_read_word(&volts_to_freq[(1024/12)*i]);

	      SID_poke(4,(waveforms[j]<<4)|(0<<2)|(0<<1)|1);
	      SID_poke(0,f);   // Send frequency to chanel
	      SID_poke(1,f>>8);
	      for(d=0;d<65000;d++)   
		_delay_us(10);
	    }
	}
    }

  /* SWEEP NOISE */
  SID_poke(4,(WAVEFORM_NOISE<<4)|(0<<2)|(0<<1)|1);
  SID_poke(0, 0x9999);
  SID_poke(1, 0x9999>>8);

  for (k=0;k<1;k++)
    for (j=0;j<4;j++)
      {
	switch (filters[j])
	  {
	  case FILTER_NOTCH:
	    SID_poke(24, (CHAN3_OFF|(1<<6)|(0<<5)|(1<<4)|VOLUME));
	    leds_set_mask(LED_LO|LED_HI);
	    break;
	  case FILTER_HP:
	    SID_poke(24, (CHAN3_OFF|(1<<6)|(0<<5)|(0<<4)|VOLUME));
	    leds_set_mask(LED_HI);
	    break;
	  case FILTER_LP:
	    SID_poke(24, (CHAN3_OFF|(0<<6)|(0<<5)|(1<<4)|VOLUME));
	    leds_set_mask(LED_LO);
	    break;
	  case FILTER_BP:
	    SID_poke(24, (CHAN3_OFF|(0<<6)|(1<<5)|(0<<4)|VOLUME));
	    leds_set_mask(LED_MID);
	    break;
	  }
	
	for (i=0;i<1024;i++)
	  {
	    int f = i << 1;
	    SID_poke(21,uu_bit_low_byte(f));     // Set filter value - 11bits
	    SID_poke(22, uu_bit_high_byte(f << 5));
	    _delay_us(10000);
	  }
      }
}

void setup () 
{
  int c, i = 0;

  PORTD = 0;
  PORTB = 0x10;   // PB4 is high to disable Chip Select
  DDRD  = 0xFE;   // Keep RxD as an input, everything else output
  DDRB  = 0xFF;

  uu_init(0);

  uu_pin_mode(PIN_TX, OUTPUT);

  uu_usart_init();
  
  uu_pin_mode(PIN_LED_I, OUTPUT);

  uu_pin_mode(PIN_MULT_IN, INPUT);

  uu_pin_mode(PIN_MULT_A, OUTPUT);
  uu_pin_mode(PIN_MULT_B, OUTPUT);
  uu_pin_mode(PIN_MULT_C, OUTPUT);
  uu_pin_mode(PIN_MULT_D, OUTPUT);

  uu_pin_mode(PIN_LED_DATA, OUTPUT);
  uu_pin_mode(PIN_LED_CLOCK, OUTPUT);
  uu_pin_mode(PIN_LED_ENABLE, OUTPUT);
  
  /* Initialise Timer 0 OC0A to 1MHz on Pin 6. */
  TIMSK2 = 0;
  TCNT2  = 0;     /* Reset timer */
  OCR2A  = 0;     /* Invert clock after this many clock cycles + 1 */
  TCCR2A = (1<<COM0B0) | (2<<WGM00);
  TCCR2B = (2<<CS00); /* Prescaler */

  _sid.waveform = WAVEFORM_NONE;
  _sid.freq_chan_1 = -1;
   _sid.freq_chan_2 = 0;
  _sid.freq_chan_3 = 0;
  _sid.pulse_width = 0;
  _sid.filter = -1;
  _sid.resonance = -1;
  _sid.filter_type = FILTER_LP;
  _sid.hp = _sid.bp = 0; _sid.lp = 1;
  _sid.chan_3_state = STATE_NONE;
  _sid.gate_off = FALSE;
  _sid.volume   = 15;
  _sid.chord_index = 0;
  
  _sid.ext_waveforms = read_chan_digital(CCHAN_EXT_WAVEFORMS);
  _sid.ext_waveforms_idx = 0;
  _sid.ext_waveforms_cnt = 0;
  
  settings_load();

  /* Give swinsid a chance to initialise... seems racey, not sure why */
  for (i=0;i<2000;i++)
    _delay_us(1000);

  /* Clear all regs */
  for(c=0; c<25;c++)
    SID_poke(c,0);

  /* Write some default values to the SID */
  SID_poke(24,15);    /* Turn up the volume */
  SID_poke(5,0);      /* Fast Attack, Decay */
  SID_poke(5+7,0);      /* Fast Attack, Decay */
  SID_poke(5+14,0);      /* Fast Attack, Decay */
  SID_poke(6,0xF0);      /* Full volume on sustain, quick release */
  SID_poke(6+7,0xF0);    /* Full volume on sustain, quick release */
  SID_poke(6+14,0xF0);   /* Full volume on sustain, quick release */
  SID_poke(4,0x21);   /* Enable gate, sawtooth waveform. */

  leds_set_mask(0);

  mcp3202_init();
    
  /* set up Timer 1 for processing input & output at 50hz (like real SID to avoid excessive noise) */
  TCCR1A = 0;                                     /* normal operation */
  TCCR1B = _BV(WGM12) | _BV(CS10) | _BV (CS12);   /* CTC, scale to clock / 1024 */
  OCR1A =  319;                                   /* compare A register value (319 * 1/clock speed * 1024) = 50hz / 20ms */
  TIMSK1 = _BV (OCIE1A);                          /* interrupt on Compare A Match */
}

void
usart_dump_controls()
{
  int i;

  /* clear screen */
  uu_usart_putc(27);
  uu_usart_puts("[2J");
  uu_usart_putc(27);
  uu_usart_puts("[H"); 

  i = read_chan_analog(CCHAN_FILT);

  uu_usart_puts("FILTER: ");
  uu_usart_puti(i);
  uu_usart_putc('\n');

  i = read_chan_analog(CCHAN_RES);

  uu_usart_puts("Res: ");
  uu_usart_puti(i);
  uu_usart_putc('\n');

  i = read_chan_analog(CCHAN_PWM);

  uu_usart_puts("PWM: ");
  uu_usart_puti(i);
  uu_usart_putc('\n');

  i = switches_read_mask();

  uu_usart_puts("Button mask: ");
  uu_usart_puti(i);
  uu_usart_putc('\n');
  
  i = read_chan_analog(CCHAN_CHORD_CV);

  i = ((i-50) * N_CHORDS) / 1000;
  
  uu_usart_puts("CHORD: ");
  uu_usart_puti(i);
  uu_usart_putc('\n');

  i = read_chan_digital(CCHAN_EXT_WAVEFORMS);
  uu_usart_puts("EXT WAVEFORMS: ");
  uu_usart_puti(i);
  uu_usart_putc('\n');

  
  i =  mcp3202_read(1);

  uu_usart_puts("VCO: ");
  uu_usart_puti(i);
  uu_usart_putc('\n');

  i =  mcp3202_read(0);

  uu_usart_puts("OSC 2: ");
  uu_usart_puti(i);
  uu_usart_putc('\n');


  uu_usart_puts("EXT waveforms: ");
  uu_usart_puti(_sid.ext_waveforms);
  uu_usart_putc('\n');

  uu_usart_puts("Filter type: ");
  uu_usart_puti(_sid.filter_type);
  uu_usart_putc('\n');

  i = read_chan_analog(CCHAN_FILTER_TYPE_CV);

  uu_usart_puts("FILTER TYPE CV: ");
  uu_usart_puti(i);
  uu_usart_putc('\n');

  i = read_chan_analog(CCHAN_WAVEFORM);

  uu_usart_puts("WAVEFORM CV: ");
  uu_usart_puti(i);
  uu_usart_putc('\n');

  i = read_chan_analog(CCHAN_RINGSYNC);

  uu_usart_puts("RING SYNC CV: ");
  uu_usart_puti(i);
  uu_usart_putc('\n');

  
}

void cycle () 
{
  static bool last_gate = 0;
  static byte switch_ignore_mask = 0;
  static bool want_tune = FALSE;
  static bool first_run = TRUE;
  static uint8_t dump = 0;
  static int previous_pitch_adc_code = 0;
  
  unsigned int f;
  uint8_t      c;
  int          i, waveform, state, chord_inv;
  bool         sync_waveform = FALSE, sync_filter = FALSE, reset_osc1 = FALSE, chord_change = FALSE;


  int          led_mask    = 0;
  byte         switch_mask = 0;
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
int main(void)
{
  setup();
  while (TRUE);
}

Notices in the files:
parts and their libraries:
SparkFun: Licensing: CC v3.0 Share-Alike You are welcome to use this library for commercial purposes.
